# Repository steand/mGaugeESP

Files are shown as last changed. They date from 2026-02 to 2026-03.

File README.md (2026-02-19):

# mGaugeESP

This software is the ESP component of mGauge.

## What is mGauge?

mGauge consists of two components connected via Bluetooth Low Energy (BLE).

## ESP32 Gauge

A measuring device with two functions, based on an ESP32-S3.

The ESP32-S3 was chosen because it supports BLE 5.0, ensuring a secure connection to the mGauge GUI.

- INA219 for measuring DC current
- Voltage: 0-26V
- Current: 0-3.2A
- Power: 0-83.2W
- 3.5" LCD display for current and voltage
- xy-fz35 as an electronic resistor

with a maximum power rating of 35W (1-25V, 0-5A)

### GUI

Qt PC software for displaying and recording measurement data

- Plotting of measured values
- Saving measured values as *.csv files.

Code is available in the  [mGaugeGUI](https://github.com/steand/mGaugeGUI) repository.

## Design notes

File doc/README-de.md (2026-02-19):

# mGaugeESP

Bei dieser Software handelt es sich um den ESP  Anteil von mGauge.

## Was is mGauge

mGauge besteht aus zwei Komponenten die über Bluetooth (BLE) verbunden sind.

### ESP32 Gauge

Auf Basis eines ESP32-S3 realisiertes Messgerät mit 2 Funktionen.

Es wurde ein ESP32-S3 gewählt da er BLE 5.0 unterstützt und damit eine sichere verbindung zum mGaugeGUI gewährleistet.

- INA219 zur Messung von Gleichstrom
  
  - Spannung: 0..26V
  - Strom: 0..3.2A
  - Leistung: 0..83.2W
  - Anzeige 3.5" LCD für Strom und Spannung
- xy-fz35 als elektronischer Widertand
  mit einer Leistung von maximal 35W (1..25V, 0..5A)

### GUI

Qt PC Software zum Anzeigen und Aufzeichnen der Messdaten

- Plot der Messwerte
- Speichern der Messwerte als *.cvs Daten.

code ist im Repositoy   [mGaugeGUI](https://github.com/steand/mGaugeGUI) vorhanden.

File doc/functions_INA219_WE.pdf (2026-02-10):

Function | Parameters | what it does
bool Init( ) | none | Initiates the INA219 with some default register values; returns true, if the INA219 is connected.
void reset_INA219( ) | none | Reset of the device.
void setCorrectionFactor( factor ) | factor (float) | If INA226 current values differ from currents measured with calibrated equipment, you can apply a factor.
void setADCMode( mode ) | INA219_BIT_MODE_9 INA219_BIT_MODE_10 INA219_BIT_MODE_11 INA219_BIT_MODE_12 INA219_SAMPLE_MODE_2 INA219_SAMPLE_MODE_4 INA219_SAMPLE_MODE_8 INA219_SAMPLE_MODE_16 INA219_SAMPLE_MODE_32 INA219_SAMPLE_MODE_64 INA219_SAMPLE_MODE_128 | Sets the ADC mode for shunt and bus voltage conversion. BIT_MODE_X: single measurement with x bit resolution SAMPLE_MODE_X: average of X measurements
void setMeasureMode( mode ) | INA219_POWER_DOWN INA219_TRIGGERED INA219_ADC_OFF INA219_CONTINUOUS + bus voltage only an current only versions | Sets continuous or triggered mode, but also power down or switches ADC off For POWER_DOWN please chose "powerDown" function since it saves the configuration
void setPGain( gain ) | INA219_PG_40 INA219_PG_80 INA219_PG_160 INA219_PG_320 | Sets the PGain value; the number is the maximum shunt voltage in mV. Using PG_320 and a 0.1 Ohm shunt sets the current range to 3.2 amperes.
void setBusRange( mode ) | INA219_BRNG_16 INA219_BRNG_32 | Bus voltage range 0-16 Volt / 0 - 32 Volt
void setShuntSizeInOhms( size ) | shuntSizeInOhms (float) | Defines the shunt size in case you don't use a shunt of 0.1 ohms. You find 0.1 ohm shunts on most modules.
void setShuntVoltOffset_mV( offset ) | offset in millivolts (float) | People have reported offsets, i.e. there is a shunt voltage although there is no current (load switched off). The function will correct the current and power.
float getShuntVoltage_mV( ) | none | Returns shunt voltage in mV
float getBusVoltage( ) | none | Returns bus voltage in mV
float getCurrent_mA( ) | none | Returns current in mA
float getBusPower( ) | none | Returns the power in mW
bool getOverflow( ) | none | Returns "true" if an overflow occurs in one of the data registers
void startSingleMeasurement( timeout ) | optional: timeout | Starts single shot measurement and waits until data is available (blocking). If timeout is passed to the function and if it is exceeded the sketch will return from the function.
void startSingleMeasurementNoWait( ) | none | Starts single shot measurement. It does not wait until data is available (non-blocking).
bool getConversionReady( ) | none | Returns true if a conversion is ready.
void powerDown( ) | none | Switches the module off and saves the configuration before.
void powerUp( ) | none | Switches the module on after Power Down and writes back the configuration (modes, gains, etc).

## List of commands (public functions) of the INA219_WE library

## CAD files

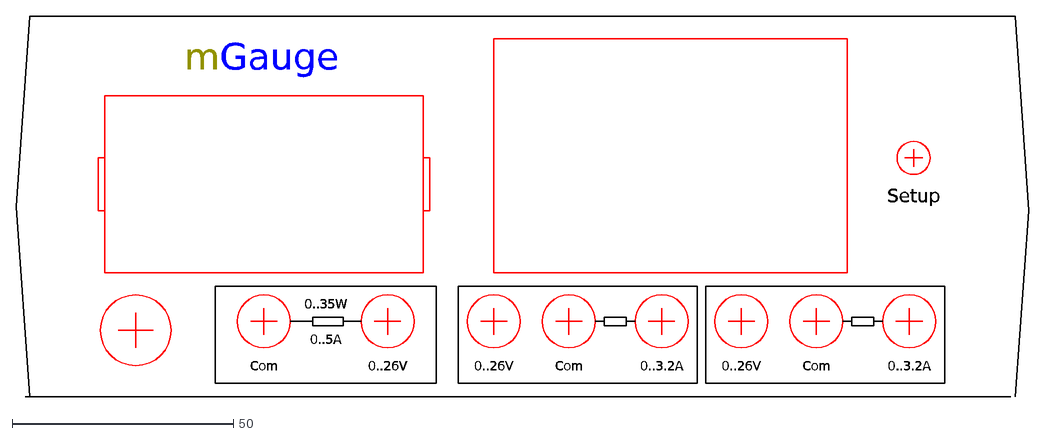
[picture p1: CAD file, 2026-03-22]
doc/#frontpanel.dxf
Gauge
m
Setup
Com
0..26V
0..3.2A
0..5A
0..35W

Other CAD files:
doc/frontpanel.dxf

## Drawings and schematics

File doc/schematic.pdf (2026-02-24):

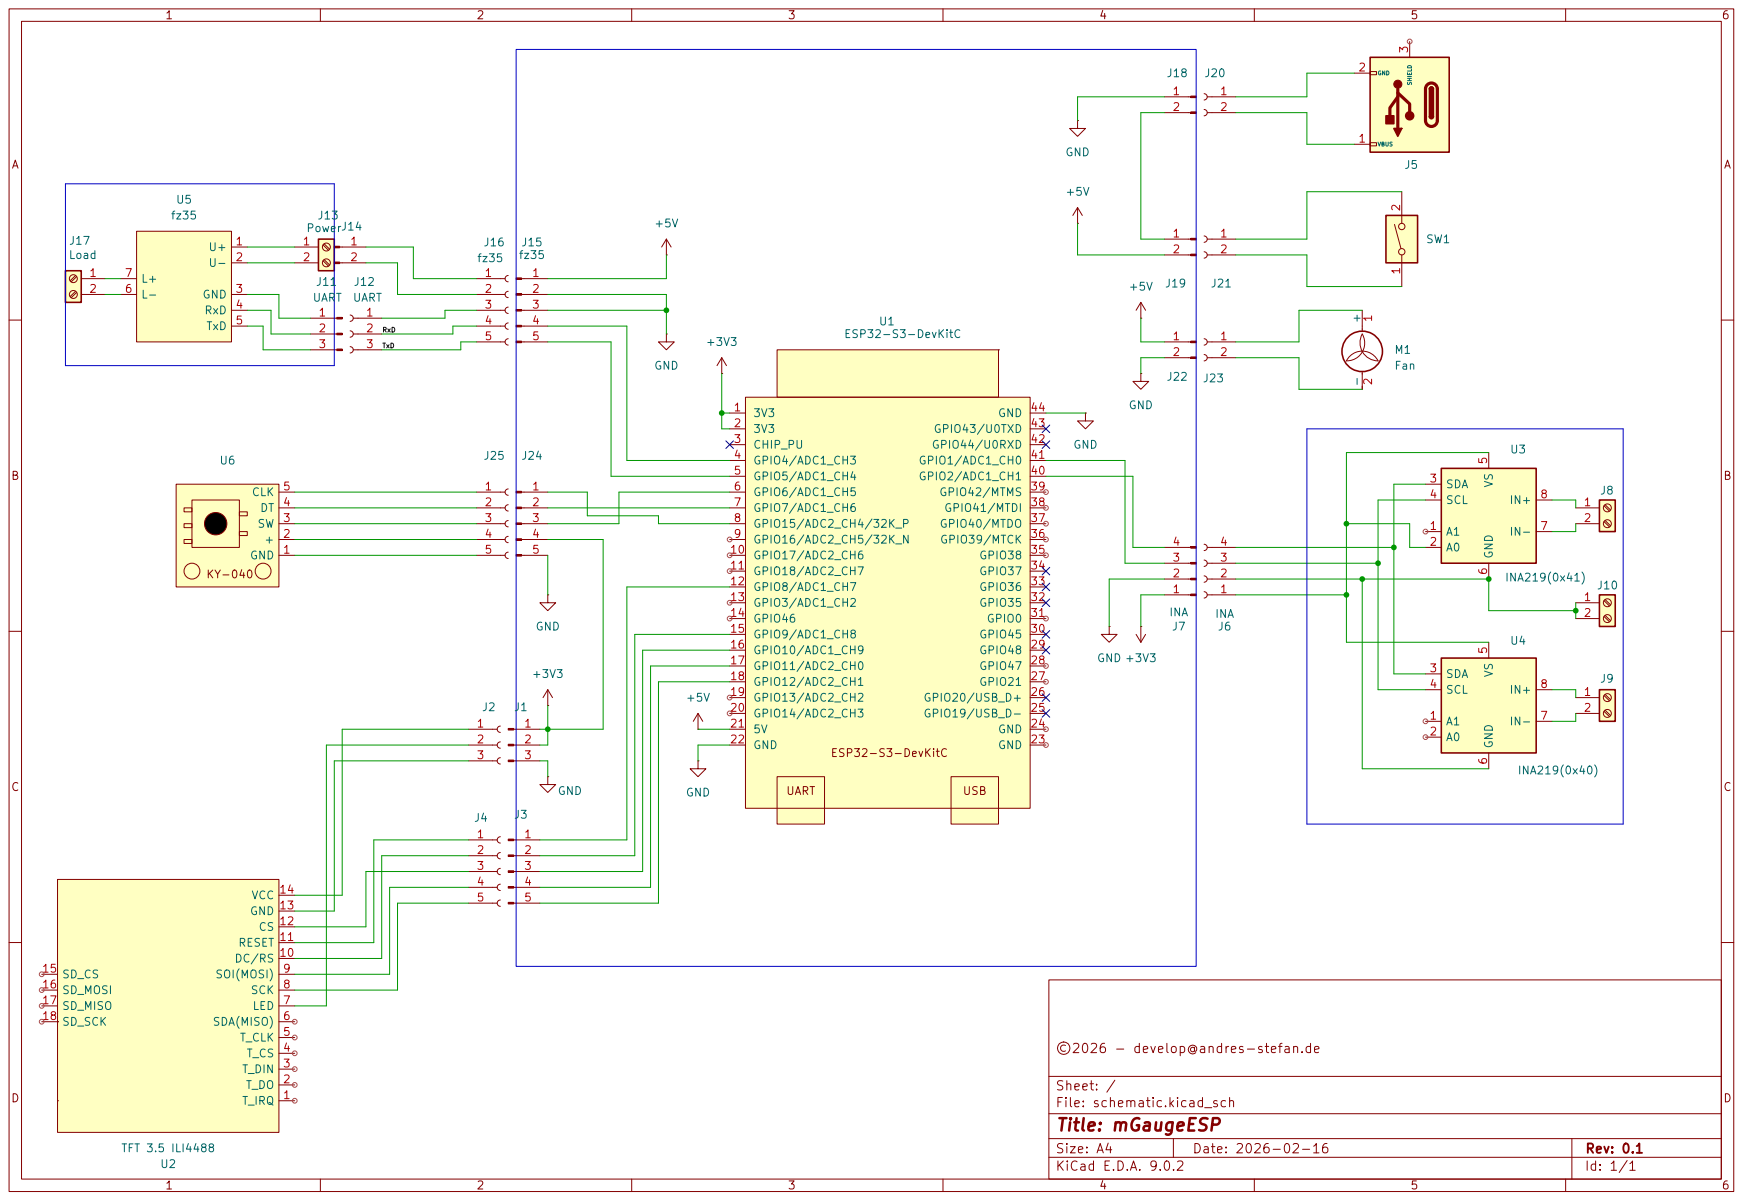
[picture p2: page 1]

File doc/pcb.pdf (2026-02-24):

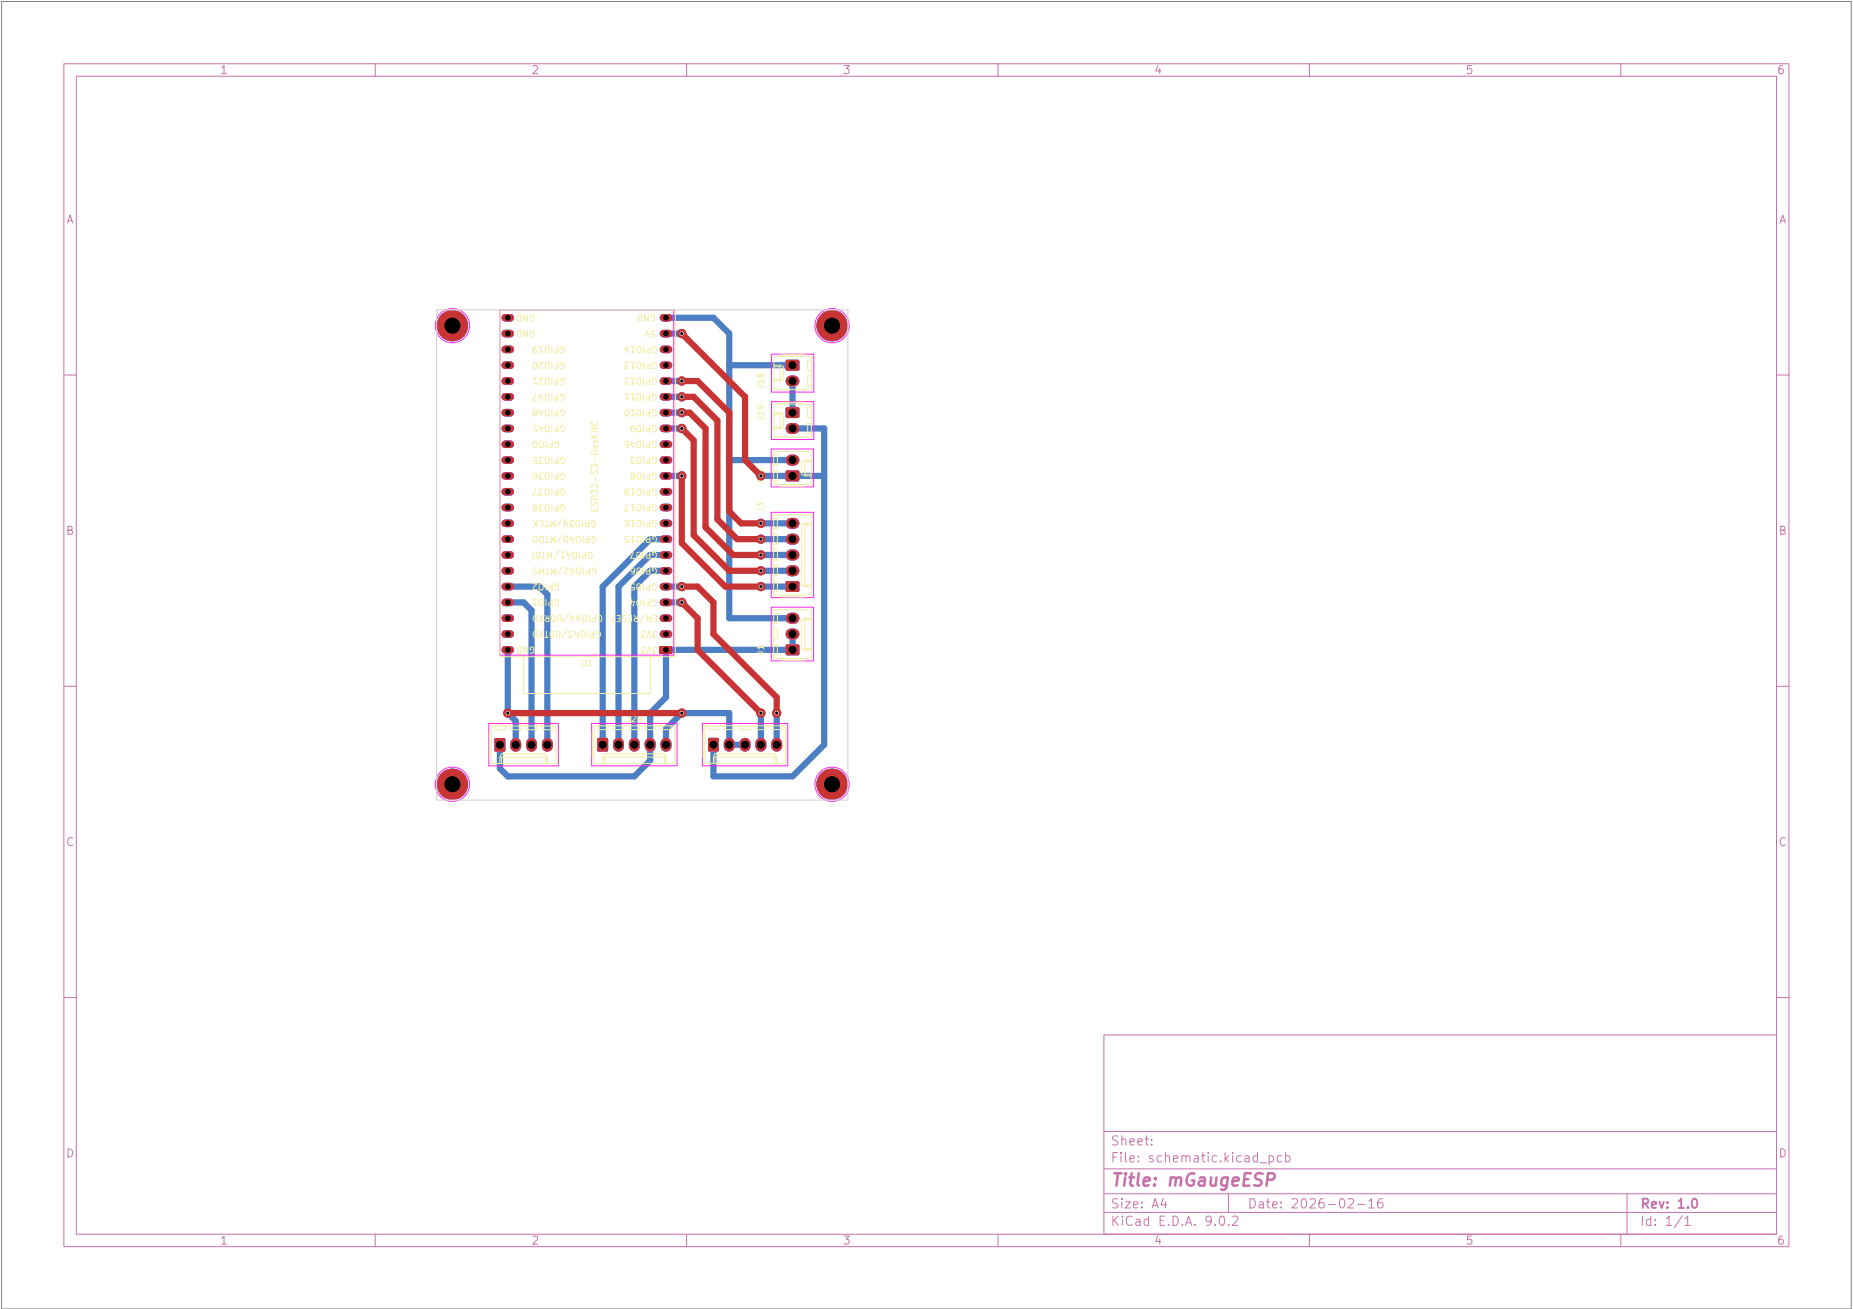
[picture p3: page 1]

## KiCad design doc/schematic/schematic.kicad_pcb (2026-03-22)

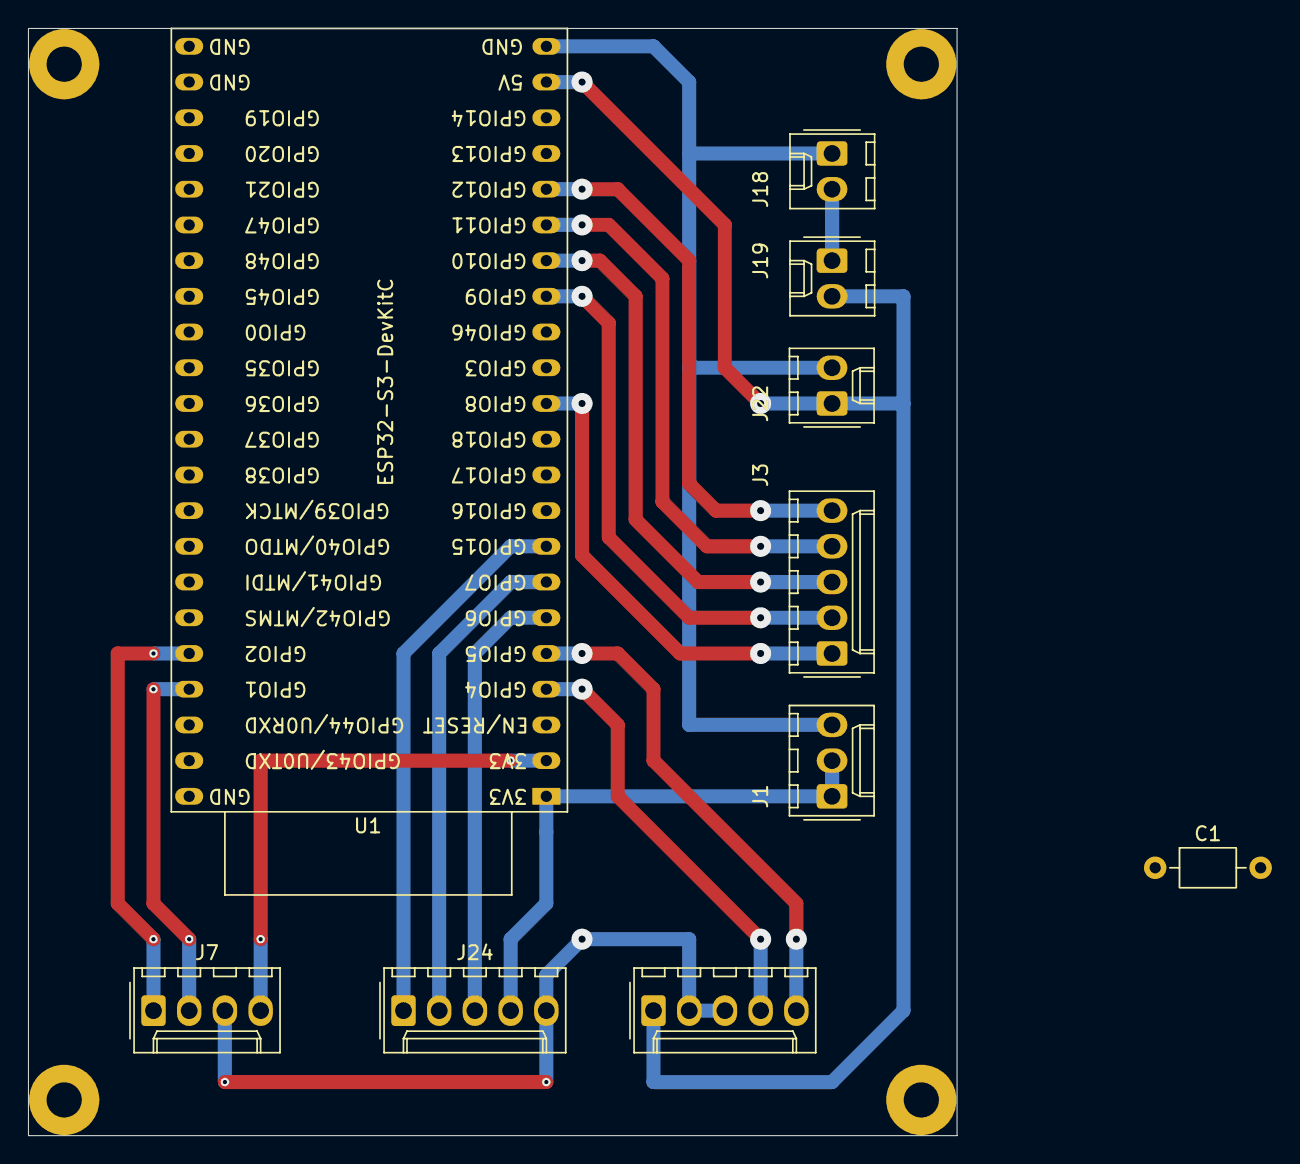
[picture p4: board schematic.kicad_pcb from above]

Board: 2 copper layers, 66.0 x 78.7 mm, 10 parts (0 on the bottom side), 16 nets.

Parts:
C1: 0,1µ; C_Axial_L3.8mm_D2.6mm_P7.50mm_Horizontal
J1: TFT_Power; Molex_KK-254_AE-6410-03A_1x03_P2.54mm_Vertical
J3: TFT; Molex_KK-254_AE-6410-05A_1x05_P2.54mm_Vertical
J7: INA; Molex_KK-254_AE-6410-04A_1x04_P2.54mm_Vertical
J15: fz35; Molex_KK-254_AE-6410-05A_1x05_P2.54mm_Vertical
J18: USB; Molex_KK-254_AE-6410-02A_1x02_P2.54mm_Vertical
J19: Switch; Molex_KK-254_AE-6410-02A_1x02_P2.54mm_Vertical
J22: Fan; Molex_KK-254_AE-6410-02A_1x02_P2.54mm_Vertical
J24: KY-040; Molex_KK-254_AE-6410-05A_1x05_P2.54mm_Vertical
U1: ESP32-S3-DevKitC

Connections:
+3V3: J1.1, J1.2, J7.4, J24.4, U1.1 (3V3), U1.2 (3V3)
+5V: C1.1, J15.1, J19.2, J22.1, U1.21 (5V)
GND: C1.2, J1.3, J7.3, J15.2, J15.3, J18.1, J22.2, J24.5, U1.22 (GND), U1.44 (GND)
unnamed: J3.1, U1.12 (GPIO8/ADC1_CH7)
unnamed: J3.2, U1.15 (GPIO9/ADC1_CH8)
unnamed: J3.3, U1.16 (GPIO10/ADC1_CH9)
unnamed: J3.4, U1.17 (GPIO11/ADC2_CH0)
unnamed: J3.5, U1.18 (GPIO12/ADC2_CH1)
unnamed: J7.1, U1.40 (GPIO2/ADC1_CH1)
unnamed: J7.2, U1.41 (GPIO1/ADC1_CH0)
unnamed: J15.4, U1.4 (GPIO4/ADC1_CH3)
unnamed: J15.5, U1.5 (GPIO5/ADC1_CH4)
unnamed: J18.2, J19.1
unnamed: J24.1, U1.8 (GPIO15/ADC2_CH4/32K_P)
unnamed: J24.2, U1.7 (GPIO7/ADC1_CH6)
unnamed: J24.3, U1.6 (GPIO6/ADC1_CH5)

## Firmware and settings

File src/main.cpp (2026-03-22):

/*
   Copyright (C) 2026  by Stefan Andres (develop@andres-stefan.de)

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
   You should have received a copy of the GNU General Public License
   along with this program.  If not, see <https://www.gnu.org/licenses/>.
 */

#include <Arduino.h>

#include "Logging.h"

#include "Data.h"

#include "BTHandler.h"
#include "INA219Handler.h"
#include "FZ35Handler.h"
#include "Display.h"


GData Data;  // Global!!!
GDisplay Display; // Global !!!

INA219Handler ina219;
FZ35Handler fz35;

BTHandler server;

void setup()
{

  _log_begin(115200);  
  delay(3000); // Wait if Powered by 5V.
   pinMode(LED_BUILTIN, OUTPUT);
   digitalWrite(LED_BUILTIN, LOW);  // On Board RGB-LED off

  _logd("Start Service Data...");
   Data.begin();

 
  _logd("Start Service <INA219>...");
   ina219.begin();

  _logd("Start Service <FZ35>...");
   fz35.begin();

   _logd("Start Service Display...");
   Display.begin(); 

   _logd("Start BLE Server <ESPTestBLE>...");
   server.start("ESPTestBLE");


}

long timer1 = millis();
boolean conected = false;
void loop()
{
  // notify changed value
  if ((millis() - timer1) > 1000)
  {

    timer1 = millis()-1;
    ina219.updateData();
    
    if (server.isConnected())
    {
      if (!conected)
      {
        Display.btConnected(true);
        fz35.start();
        Display.fz35Connected(true);
        conected = true;
        _log("Client conected");
      }
      fz35.updateData();
      server.send();
    }
    else
    {
      if (conected)
      {
        Display.btConnected(false);
        fz35.stop();
        Display.fz35Connected(false);
        conected = false;
        _log("Client disconected");
      }
    } 
    
  }
  ina219.loop();
  fz35.loop();
 
}

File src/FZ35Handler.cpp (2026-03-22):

/*
   Copyright (C) 2026  by Stefan Andres (develop@andres-stefan.de)

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
   You should have received a copy of the GNU General Public License
   along with this program.  If not, see <https://www.gnu.org/licenses/>.
 */

#include "FZ35Handler.h"

// #define TESTDATA_ON



void FZ35Handler::begin()
{
    fxSerial.begin(9600,SERIAL_8N1, FZ35_RxT_PIN, FZ35_TxT_PIN);
    // pinMode(5,INPUT);
    voltage =5.5;
    current =2.0;
    capacity = 0.0;
    time = 0;
    fxSerial.print("stop\r\n");
}

void FZ35Handler::start()
{
     fxSerial.print("start\r\n");
     _log("FZ35 Started");
}

void FZ35Handler::stop()
{
    fxSerial.print("stop\r\n");
    _log("FZ35 Stoped");
}


void FZ35Handler::loop()
{
    
#ifdef TESTDATA_ON
   return;
#endif   

    char ch;

    while (fxSerial.available() > 0)
    {

        ch = fxSerial.read();
       //  _logd("FZ35 char : %d = %c", ch, ch);

        switch (ch)
        {
        case 10:
            pos = 0;
            break;
        case 13:
             _logd("Fz35 data: %s", inStr.c_str());
            switch (pos)
            {
            case 0:
                voltage = inStr.toFloat();
                break;
            case 1:
                current = inStr.toFloat();
                break;
            case 2:
                capacity = inStr.toFloat();
                break;
            case 3:
                time = inStr.toInt() * 60;
                inStr.remove(0, inStr.indexOf(':') + 1);
                time += inStr.toInt();
                break;
            default:
                _loge("Wrong pos #%d", pos);
                break;
            }
            pos++;
            inStr = "";
        case 32:
            break; // delete space
        default:
            inStr += String(ch);
        }
    }
}


boolean FZ35Handler::updateData()
{
    Data.setFzVoltage(voltage);
    Data.setFzCurrent(current);
    Data.setFzCapacity(capacity);
    Data.setFzTime(time);

#ifdef TESTDATA_ON
    Data.setFzVoltage(21.0);
    Data.setFzCurrent(4.2);
    Data.setFzCapacity(2.7);
    Data.setFzTime(128);
#endif

    return true;
}

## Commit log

2026-02-12 Add schematic
    add schematic build with KiCad
    [schematic.kicad_pcb, schematic.kicad_sch]
2026-02-16 Schema V0.1
    [schematic.kicad_pcb, schematic.kicad_sch]
2026-02-19 Add 2nd INA219 & modify display.
    ToDo: implementation of FZ35
    [schematic.kicad_pcb, schematic.kicad_sch]
2026-02-21 full functionality
    [schematic.kicad_pcb, schematic.kicad_sch]
2026-02-24 code optimization
    1.) centralization of data in a global class
    2.) make Display as a global class
    3.) code optimization
    4.) prepare for a setup dialog
    this version not able for production
    [schematic.kicad_pcb, schematic.kicad_sch]
2026-02-24 Stable for testing
    all functions avalible:
    1. INA219 complete
    1.1 KY-040 and dialog for setup INA219 Resistor
    2. Fz35 ready to send data to bluetooth
    3. Bluetooth already but not tested
    doc:
    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
2026-02-24 update schematic
    [schematic.kicad_pcb]
2026-03-22 Bug Fix for V1.0.0-pre_alpha
    [#frontpanel.dxf, frontpanel.dxf, schematic.kicad_pcb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]

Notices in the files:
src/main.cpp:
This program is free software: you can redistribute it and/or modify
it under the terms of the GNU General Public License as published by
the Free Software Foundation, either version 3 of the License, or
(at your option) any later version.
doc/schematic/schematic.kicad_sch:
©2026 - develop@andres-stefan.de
